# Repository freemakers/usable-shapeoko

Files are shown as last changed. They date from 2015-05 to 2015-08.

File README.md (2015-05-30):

# Making Shapeoko Usable for Mere Mortals

The basic Shapeoko 2 kit comes with the parts and instructions necessary to print out the nice little "Shapeoko 2" logo on a piece of paper. It feels really good to see that print out after all the intricate assembly (mine is still hanging on the wall of my shop).

## Now What?

But try to mill anything else, and you have a lot of new problems to solve. How can you design a new part? Once you've designed it, how do you turn it into gcode? How do you even feed the gcode to the mill?

As with many things, all of these questions are easy to answer if you're running Windows and can afford the price of your Shapeoko 2 kit again in software. If you use Linux or want to use open source tools to design your parts, compile gcode, or control your mill, you'll suddenly find yourself alone in the dark.

## Project Purpose

This project will serve primarily as a repository for documentation on how to get Shapeoko 2 running with an open source toolchain, along with a notebook on hardware mods and associated programming that should make the Shapeoko 2 more user-friendly.

Most of this project will be stored in the `gh-pages` branch, which will be used to automatically publish notes and documentation to a generated website on http://freemakers.github.io.

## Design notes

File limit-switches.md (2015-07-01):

---
title: "Homing and Limit Switches"
---

### Overview

Homing switches should make it possible to find 0,0 coordinate in the X-Y plane without manual orientation. Limit switches should provide feedback when the machine tries to move beyond the safe limits of its axes (which could damage the machine). In all cases, these should be binary on/off switches with as little bounce or travel between on and off as possible. The ubiquitous rocker switch seems like a reasonable, if not incredibly precise, place to start this work. The benefit of rocker switches is that nearly anything that will work with a rocker switch will also work with some other kind of switch (except the details of the brackets).

### Notes

* cheap rocker switches should do the trick
  * not clear what accuracy they provide though
* Motor plates are a good place to mount switches for X and Y
  * Wiring from here should be simple, since it can follow existing paths
  * Needs a mounting bracket that fits into the slot on the side of the plate
  * Bracket can be cut for threading by the machine screw if printed (the material is soft enough)...no nut required

### Selections / Solutions

#### X-Y Axis Brackets

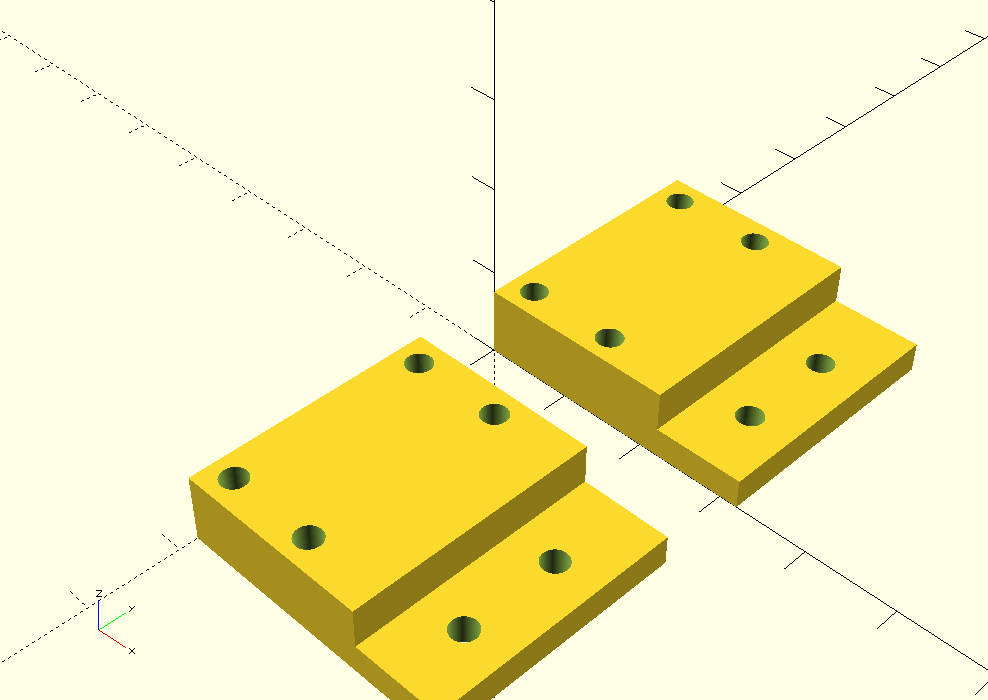
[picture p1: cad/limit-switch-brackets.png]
Custom Limit Switch Bracket


* [Custom limit switch bracket (SCAD)](cad/limit-switch-brackets.scad) [(STL)](cad/limit-switch-brackets.stl) - created by John and Zack
  * Bracket sleeves between Makerslide and motor panel
  * Machine screws attach to low side of bracket through slot in motor panel side
  * High side of bracket sits flush with side of motor panel
  * **Overall dimensions:** 32mm x 28mm x 3.25mm (low side) / 7.6mm (high side)
  * Notes:
	 * 15mm M3 machine screw is a slightly too small to mount through the rocker switch (you get about two threads' worth of bite in the bracket at best)
  	 * 15mm screw is a little too tall for mounting the bracket onto the motor plate
        * using two M3 2.4mm thick nuts as spacers here works beautifully
     * No nuts are required for fastening to the bracket; M3 machine screw will cut its own threads through the material

#### Limit/Homing Switches

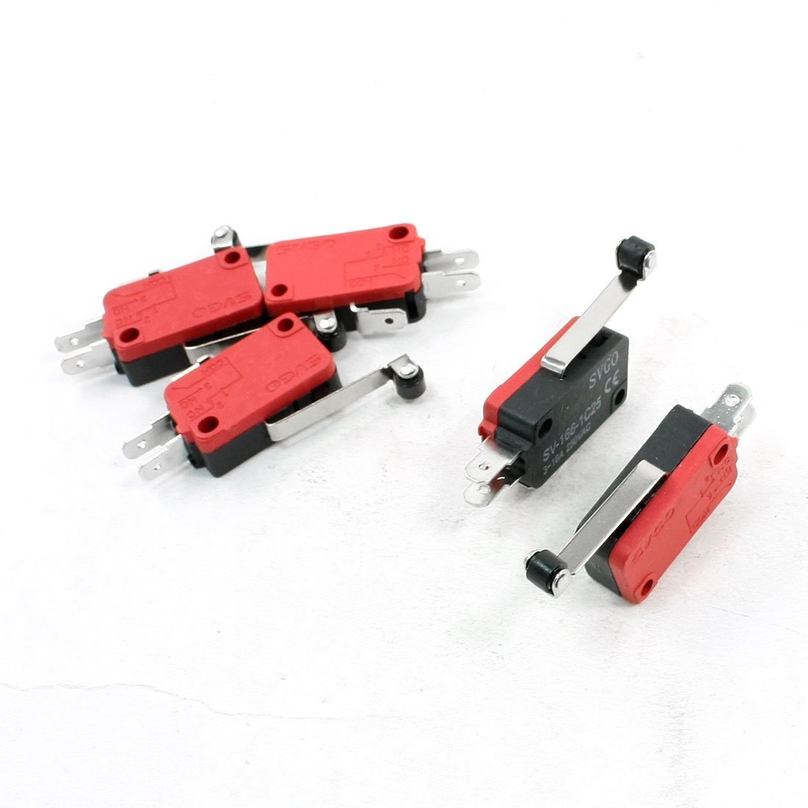
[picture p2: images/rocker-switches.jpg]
Cheap Rocker Switches (http://www.amazon.com/gp/product/B00H8TIEHW/ref=oh_aui_detailpage_o00_s00?ie=UTF8&psc=1)


* [Cheap rocker switches](http://www.amazon.com/gp/product/B00H8TIEHW/ref=oh_aui_detailpage_o00_s00?ie=UTF8&psc=1)
  * M3 machine screws fit the mounting holes perfectly, but leftover 15mm screws from Shapeoko 2 build are slightly too short.
  * Switch body is 10mm thick.

### Potential Solutions for Z Axis

#### Materials

* [Post-assembly T-slot nuts](https://www.inventables.com/technologies/post-assembly-t-slot-nuts) for makerslide

#### Prints

* [Rear-mounted, right-angle bracket](https://www.thingiverse.com/thing:408063)

### Wiring / Configuration Instructions

* [Shapeoko site's doc](http://www.shapeoko.com/wiki/index.php/Home/Limit_Switches)
* [Connecting to grbl](https://github.com/grbl/grbl/wiki/Connecting-Grbl)

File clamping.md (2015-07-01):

---
title: "Clamping & Work-Holding"
---

### Overview

Our goal here is to provide a set of tools for holding down a piece of work as the CNC does its thing. With larger mills, there could be some significant lateral pressure on the work, so for big woodworking jobs we will want some heavier duty clamps. At the same time, we need a different (additional) solution for PCBs, where we will want to mill right out to the ends of the copper clad. There, a small vacuum table solution might work best. This page is meant to capture some of these requirements and ideas.

### Notes

* It would be nice to have a good base system that can stand up to some abuse
* It would also be nice to have add-on vacuum table-type boxes that could be clamped to the main body

### Large Item Holding / Large Work Margins

#### Clamp Designs

* [2-Bolt Slotted Clamp](cad/2-bolt-slotted-clamp.scad) [(STL)](cad/2-bolt-slotted-clamp.stl) - created by John
  * Designed for 1/4"-20 hardware
  * Upside-down carriage bolt as a lever point / spacer
  * Hex head bolt for tightening
    * Threads into t-bolt in wasteboard
  * Knurled work-holding end for better grip / more grip options
  * Rounded ends to limit potential for damage to the work 

### Small Items / Little or No Work Margins

#### Vacuum Designs on the Web

* [via Makezine](http://makezine.com/projects/make-41-tinkering-toys/shopbot-desktop-universal-vacuum-hold-down-system/)
* [YouTube](https://www.youtube.com/watch?v=fOrkvPF0pro)
* [Massively complicated one on Instructables](http://www.instructables.com/id/Vacuum-Clamping-Table-for-Homebrew-CNC/)
* [Smaller Instructable](http://www.instructables.com/id/Vaccum-Table-for-Mini-CNC-Milling-Machine/) (useful comments section for sealing against the work)

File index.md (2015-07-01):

---
permalink: '/index.html'
---

### Overview

It seems a little crazy that after spending over $700 on the Shapeoko 2 CNC mill, you still have a lot of simple yet nagging problems to work through before you have a system that is reasonably easy to work with. Things like rocker switches, pin switches, and the associated brackets are dirt cheap, and could be provided as part of the Shapeoko 2 kit. If you opted to upgrade them, then of course you have that option, but at least this would give you some basic homing and protection options.

### The Problems

The Shapeoko 2 kit is fairly easy to assemble, and once you get it put together it's not too hard to print out the little "Shapeoko 2" logo using a Sharpie. But going much beyond that, you can quickly find that what you really need now is $300 or so worth of software. Trying to use an open-source toolchain is a long and bumpy road, and full of a lot of hard lessons. 

Beyond software, the basic Shapeoko itself leaves something to be desired. While it's capable of sub-millimeter precision, it's lack of homing switches means finding an accurate starting point is a manual task. This in turn means whatever depth you plan for pocket operations is an estimate. And if you design a cut bigger than your cutting area, there's nothing to stop your Shapeoko from trying anyway.

Specifically, these are the problems this project will try to address:

#### Hardware

* [No homing/limit switches](limit-switches.html)
* [Probe to home Z axis](z-probe.html)
* [Clamping / Work-holding](clamping.html)
* [Measuring material dimensions](material-dimensions.html)
* [Computer / Arduino management](electronic-management.html)
* [Dust Management](dust-management.html)

#### Software

* [Open source CAM software is a mess](cam.html)
  * pyCAM needs python 2.6, which is getting harder to come by
  * pyCAM isn't all that healthy as software projects go...
* [gcode isn't gcode](gcode-processing.html)
  * some CAM software doesn't generate gcode compatible with grbl

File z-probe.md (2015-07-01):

---
title: "Z-Probe"
---

### Overview

The Z-probe should allow the CNC a known location on the workspace to plunge the tool (when it's turned off!) and find its 0-coordinate. Along with homing switches for X and Y, this should allow the machine to zero itself out before beginning a job. The probe should work regardless of how far the tool protrudes from the Z-axis sled (it should accommodate different tool lengths).

### Notes

* A simple pin switch might be a good place to start

### Potential Materials

* [2" Pin Switch](http://www.amazon.com/CES-2-Adjustable-Pin-Switch/dp/B0002ZPBHU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) (via Amazon)

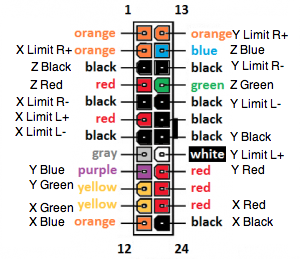
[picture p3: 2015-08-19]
images/ATX24-Quick-Disconnect.png

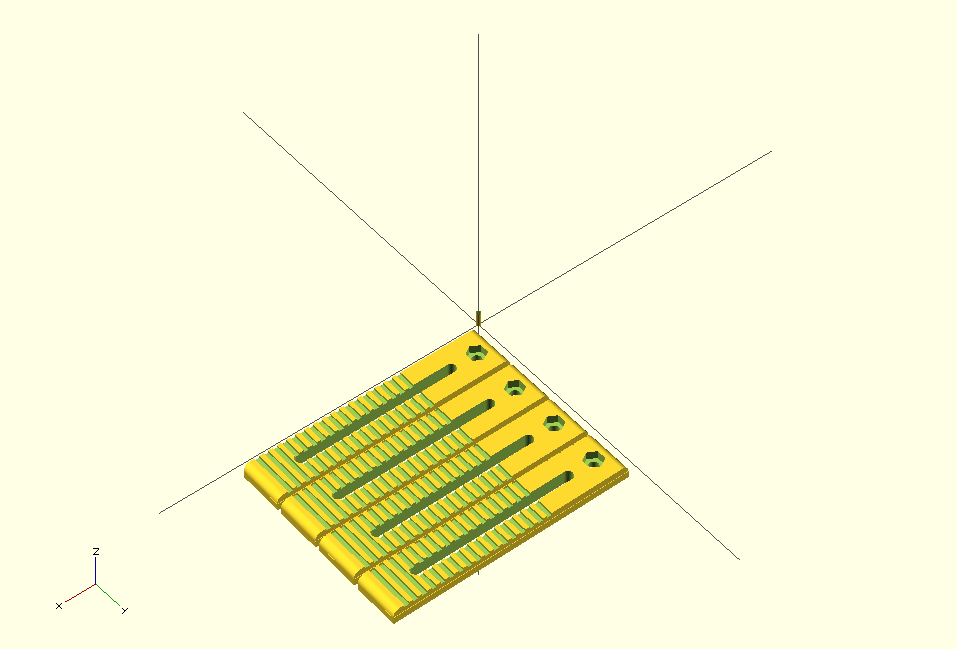
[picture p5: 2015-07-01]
cad/2-bolt-slotted-clamp.png

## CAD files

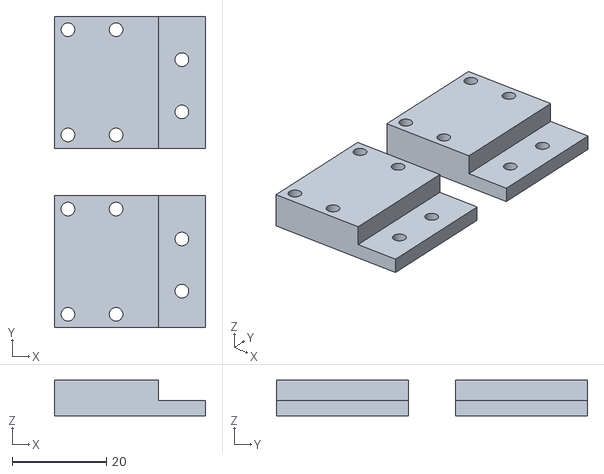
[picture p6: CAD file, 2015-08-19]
cad/limit-switch-brackets.stl
32.0 x 66.0 x 7.60

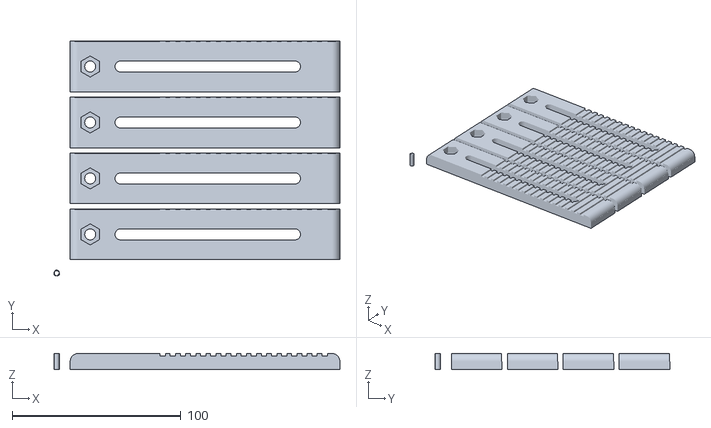
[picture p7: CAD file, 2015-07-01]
cad/2-bolt-slotted-clamp.stl
169.5 x 139.1 x 9.60

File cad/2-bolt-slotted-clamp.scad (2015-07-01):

$fn=100;

q20_bolt_diam = 6.5;
material_z = 9.6;
bit_width = 3.175;

base_x = 160;
base_y = 30;
base_z = material_z;

hole_r = q20_bolt_diam / 2;
hole_y_off = base_y / 2;
hole_z_off = base_z / 2;

nut_face_sep = 10.85;
nut_point_sep = 12.35;
nut_z = 5.5;

nut_ctr_x_off = (hole_r *2)+ (nut_face_sep / 2);
nut_ctr_y_off = hole_r + (nut_point_sep / 2);
nut_z_off = base_z - (nut_z/2);

slot_x = base_x * 2/3;
slot_x1_off = hole_r + (base_x - slot_x)/2;
slot_x2_off = slot_x1_off + slot_x - hole_r;
slot_z = base_z;

module knurls(){
	cuts = [0:16];
	increment = 6;
	depth= bit_width/2;
	start=base_x/3;

	union(){
		for(cut=cuts){
			translate([(cut*increment) + (start), -.1, base_z-depth])
				cube([bit_width, base_y, depth]);
		}
	}
}

module hex(d,z){
  passes = [0:2];
  chord=d*1/tan(60);

  union(){
     for(pass=passes){
       rotate([0,0,pass*60]) cube(size=[d,chord,z],center=true);
     }
  }
}

module fastenerCuts(){
	union(){
   		translate([nut_ctr_x_off,hole_y_off,nut_z_off])
			hex(nut_face_sep,nut_z);

   		translate([nut_ctr_x_off,hole_y_off,hole_z_off])
			cylinder(r=hole_r,h=base_z, center=true);

		hull(){
			translate([slot_x1_off,hole_y_off,hole_z_off]) 
				cylinder(r=hole_r,h=slot_z, center=true);
			translate([slot_x2_off,hole_y_off,hole_z_off]) 
				cylinder(r=hole_r,h=slot_z, center=true);
		}
	}
}

module block(){
	union(){
		translate([base_z/2,0,base_z/2])
		rotate([-90,0,0])
			hull(){
				cylinder(d=base_z*.99,h=base_y*.99, center=false);
				translate([base_x - base_z,0,0])
					cylinder(d=base_z*.99,h=base_y*.99, center=false);
			}
		cube([base_x,base_y,base_z/2]);
	}
}

module clamp(){
  difference(){
		block();
		fastenerCuts();
		knurls();
  }
}

module clamps(){
	increment = base_y + bit_width;
	parts = [0:3];
	union(){
		for(part=parts){
			translate([0, (increment*part), 0]) clamp();
		}
	}
}

module index(){
	ctr=bit_width*1.01/2;
	difference(){
		translate([0, 0, base_z/2])
			cylinder(r=ctr, h=base_z, center=true);
		translate([0, 0, base_z/2])
			cylinder(r=bit_width/2, h=base_z, center=true);
	}
}

module sheet(){
	union(){
		index();
		translate([bit_width*5/2, bit_width*5/2, 0]) clamps();
	}
}

sheet();

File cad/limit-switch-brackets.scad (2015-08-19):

$fn=100;

mm=1;

switch_z=10*mm;

base_x=32*mm;
base_y=28*mm;
base_z=3.25*mm;

layer2_z=7.6*mm-base_z;

riser_x=22*mm;
riser_y=base_y;
riser_z=layer2_z;

riser_x_off=0;
riser_y_off=0;
riser_z_off=base_z;

hole_r=2.9*mm/2;
hole_z=base_z + layer2_z;

hole_y_off=1.4*mm + hole_r;

hole1_x_off=11.6*mm + hole_r;
hole2_x_off=hole_y_off;

hole1_L_y_off=hole_y_off;
hole2_L_y_off=base_y-hole_y_off;

hole1_R_y_off=base_y-hole_y_off;
hole2_R_y_off=hole_y_off;

tab_x=2.8*mm;
tab_y=12.5*mm;
tab_z=layer2_z + 3;

tab_x_off=riser_x+3.6*mm + (tab_x/2);
tab_y_off=(base_y-tab_y)/2;
tab_z_off=base_z;

module base(){
   cube([base_x, base_y, base_z]);
}

module tab(x_off, y_off, z_off, x, y, z){
	hull(){
		translate([x_off, y_off, z_off])
			cylinder(d=x, h=z);
		translate([x_off, y_off+(y), z_off])
			cylinder(d=x, h=z);
	}
}

module layer2(){
	translate([riser_x_off, riser_y_off, riser_z_off])
		cube([riser_x, riser_y, riser_z]);
}

module bottom_holes(){
	union(){
		translate([hole1_x_off, hole1_L_y_off, 0])
			cylinder(r=hole_r, h=hole_z);
		translate([hole2_x_off, hole2_L_y_off, 0])
			cylinder(r=hole_r, h=hole_z);
        
		translate([hole1_x_off, hole1_R_y_off, 0])
			cylinder(r=hole_r, h=hole_z);
		translate([hole2_x_off, hole2_R_y_off, 0])
			cylinder(r=hole_r, h=hole_z);
        
		translate([tab_x_off, tab_y_off, 0])
			cylinder(r=hole_r,h=base_z);
		translate([tab_x_off, tab_y_off+tab_y-hole_r, 0])
			cylinder(r=hole_r,h=base_z);
	}
}

module bracket(){
	difference(){
		union(){
		   	base();
   			layer2();
		}
		bottom_holes();
	}
}

module axis_brackets(){
	bracket();
	translate([0,-(base_y+10),0]) bracket();
}

union(){
    axis_brackets();
//    translate([-(base_x+10),0,0]) axis_brackets();
}

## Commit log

2015-06-01 Adding section for selected materials/parts/prints
2015-07-01 Adding OpenSCAD file + STL for limit switch bracket that seems like it's going to work for X and Y axes.
    [limit-switch-brackets.scad, limit-switch-brackets.stl]
2015-07-01 adding a few more pages with some basic notes, and updating the limit/homing switch page with things we've learned by printing and trying a couple of brackets. Adding CAD files for a basic clamp and 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
    [2-bolt-slotted-clamp.scad, 2-bolt-slotted-clamp.stl]
2015-07-01 fixing broken STL links
2015-07-01 adding image for limit switch bracket and incorporating in MD file.
2015-07-01 cleaning up markup a bit and adding image of rocker switches
2015-07-01 storing rocker switch image locally
2015-07-01 Adding more description to bracket section
2015-07-03 layout with four switch brackets.
    [limit-switch-brackets.scad, limit-switch-brackets.stl]
2015-08-19 limit to one axis worth of brackets, and make brackets L-R universal.
    [limit-switch-brackets.scad]
2015-08-19 new rendering of brackets
2015-08-19 update STL
    [limit-switch-brackets.stl]
2015-08-19 Adding ATX wiring adapter for mill quick disconnect
